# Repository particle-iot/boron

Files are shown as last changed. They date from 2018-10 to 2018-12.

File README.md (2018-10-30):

# Boron

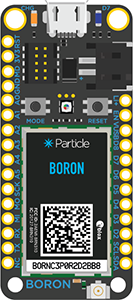
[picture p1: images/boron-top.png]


### Overview

The Boron LTE is a powerful LTE CAT-M1/NB1 enabled development kit that can act as either a standalone cellular endpoint or LTE enabled gateway for Particle Mesh networks. It is based on the Nordic nRF52840 and has built-in battery charging circuitry so it’s easy to connect a Li-Po and deploy your local network in minutes.

The Boron is great for connecting existing projects to the Particle Device Cloud or as a gateway to connect an entire group of local endpoints where Wi-Fi is missing or unreliable.

### Features

* u-blox SARA R410 LTE modem (Boron LTE)
  * LTE CAT M1/ NB1 module with global hardware support (MVNO support for US only) 
  * 3GPP Release 13 LTE Cat M1 
* u-blox SARA U201 2G/3G modem (Boron 2G/3G)
  * HSPA/GSMqq with global hardware and SIM support 
  * Bands 800/850/900/1900/2100 MHz 
  * 3GPP Release 7 
* Nordic Semiconductor nRF52840 SoC 
  * ARM Cortex-M4F 32-bit processor @ 64MHz 
  * 1MB flash, 256KB RAM 
  * IEEE 802.15.4-2006: 250 Kbps 
  * Bluetooth 5: 2 Mbps, 1 Mbps, 500 Kbps, 125 Kbps 
  * Supports DSP instructions, HW accelerated Floating Point Unit (FPU) calculations 
  * ARM TrustZone CryptoCell-310 Cryptographic and security module 
  * Up to +8 dBm TX power (down to -20 dBm in 4 dB steps) 
  * NFC-A tag
* On-board additional 2MB SPI flash
* 20 mixed signal GPIO (6 x Analog, 8 x PWM), UART, I2C, SPI
* Micro USB 2.0 full speed (12 Mbps)
* Integrated Li-Po charging and battery connector
* JTAG (SWD) Connector
* RGB status LED
* Reset and Mode buttons
* Dual SIM support: Nano 4FF and MFF2
* On-board PCB antenna
* u.FL connector for external antenna
* Meets the Adafruit Feather [specification](https://learn.adafruit.com/adafruit-feather/feather-specification) in dimensions and pinout
* FCC and PTCRB certified
* RoHS compliant (lead-free)

### Structure of this repository:
 - /eagle
     + Contains the schematic and PCB files in the Eagle file format
 - /gerbers
     + Contains the manufacturing gerber files for the board
 - /datasheets
     + Contains the relevant datasheets of the components used on the Boron
 - /pdfs
     + Contains schematic files in PDF 

### Hardware datasheet

The complete datasheet for the Boron is available [here.](https://docs.particle.io/datasheets/cellular/boron-datasheet/
)

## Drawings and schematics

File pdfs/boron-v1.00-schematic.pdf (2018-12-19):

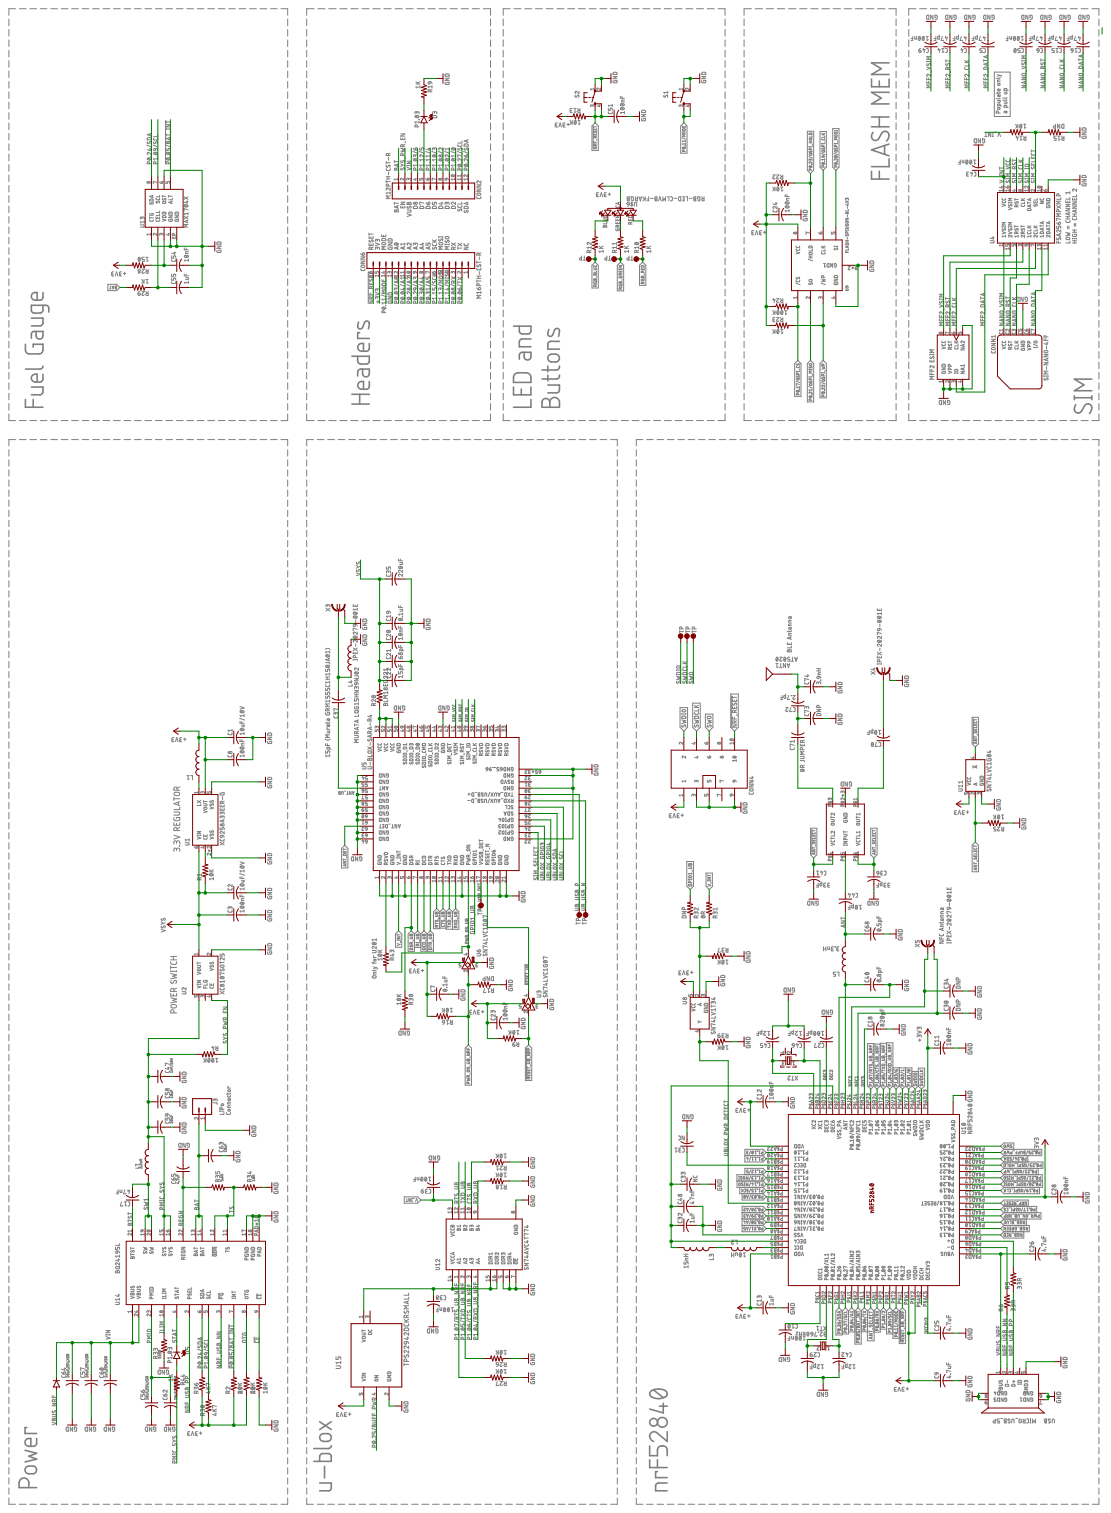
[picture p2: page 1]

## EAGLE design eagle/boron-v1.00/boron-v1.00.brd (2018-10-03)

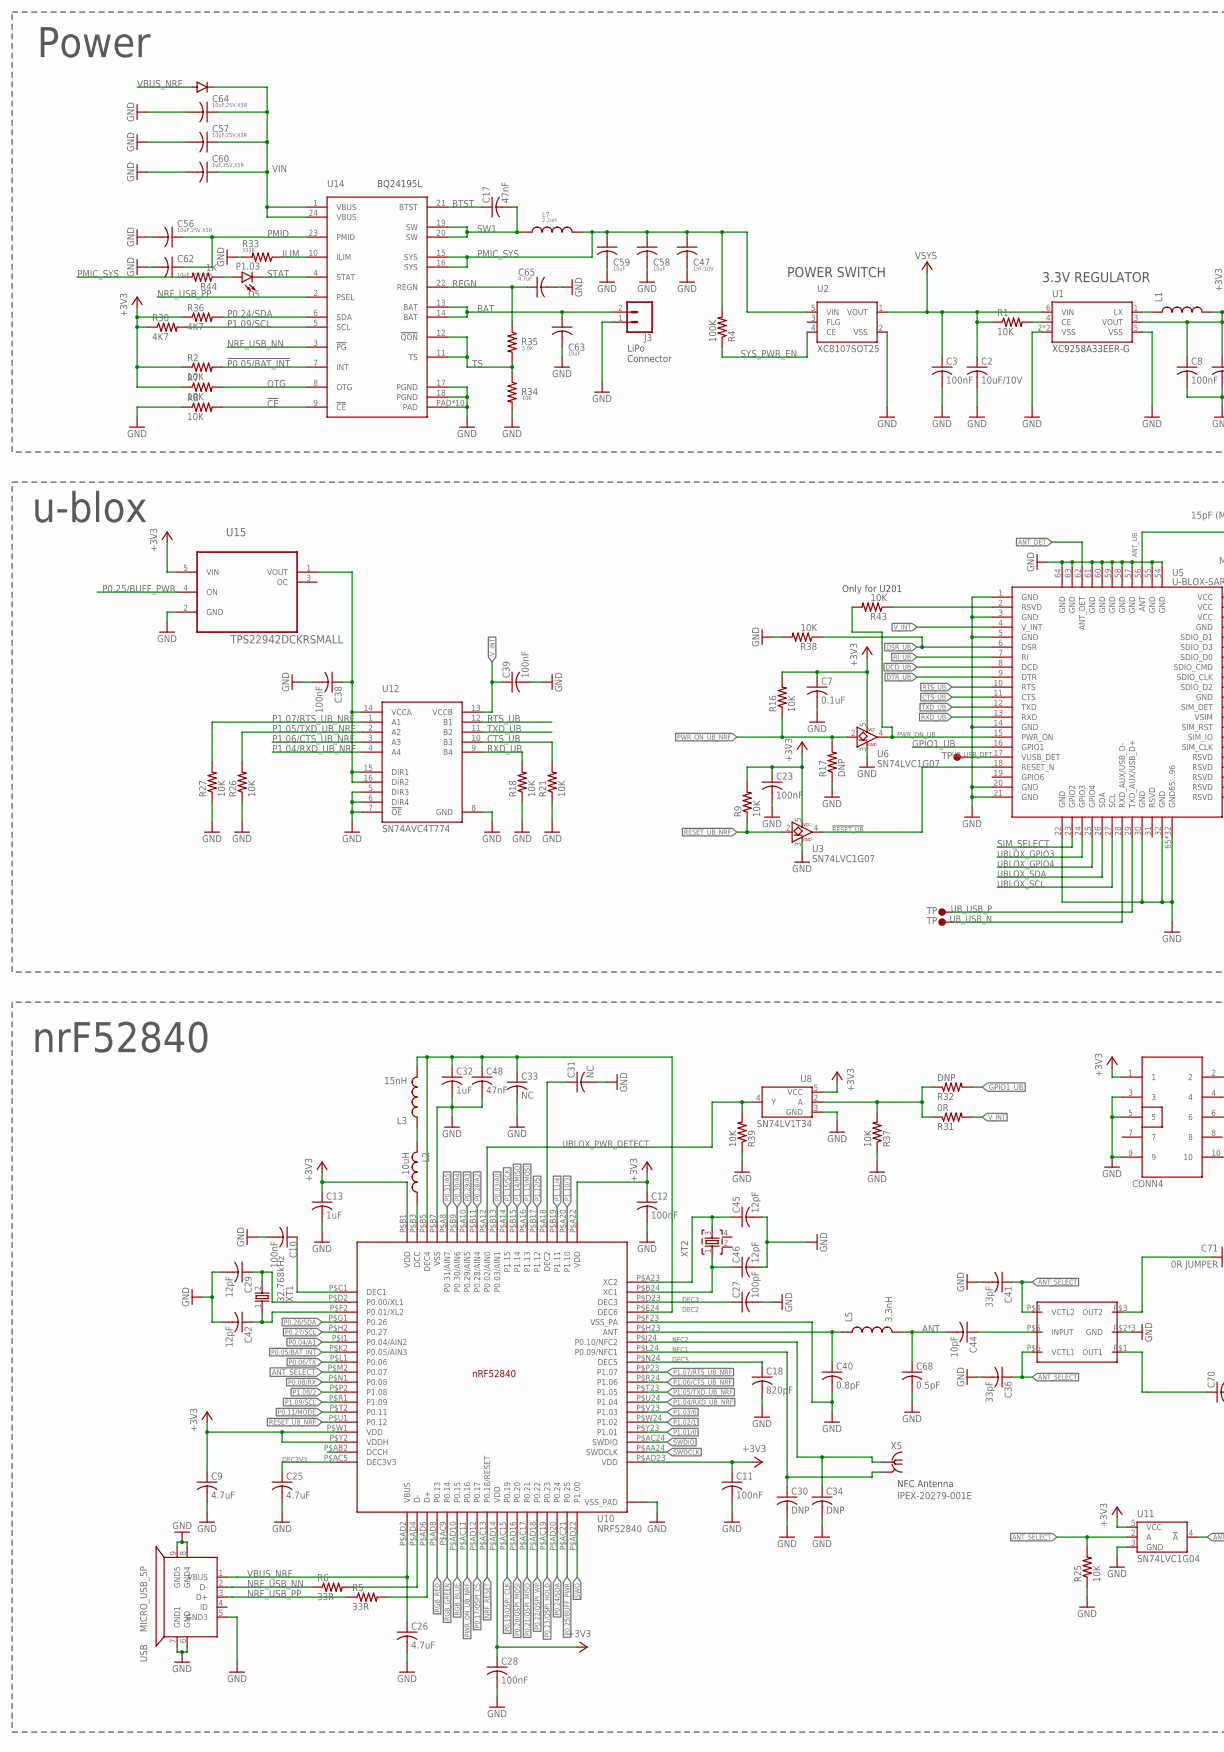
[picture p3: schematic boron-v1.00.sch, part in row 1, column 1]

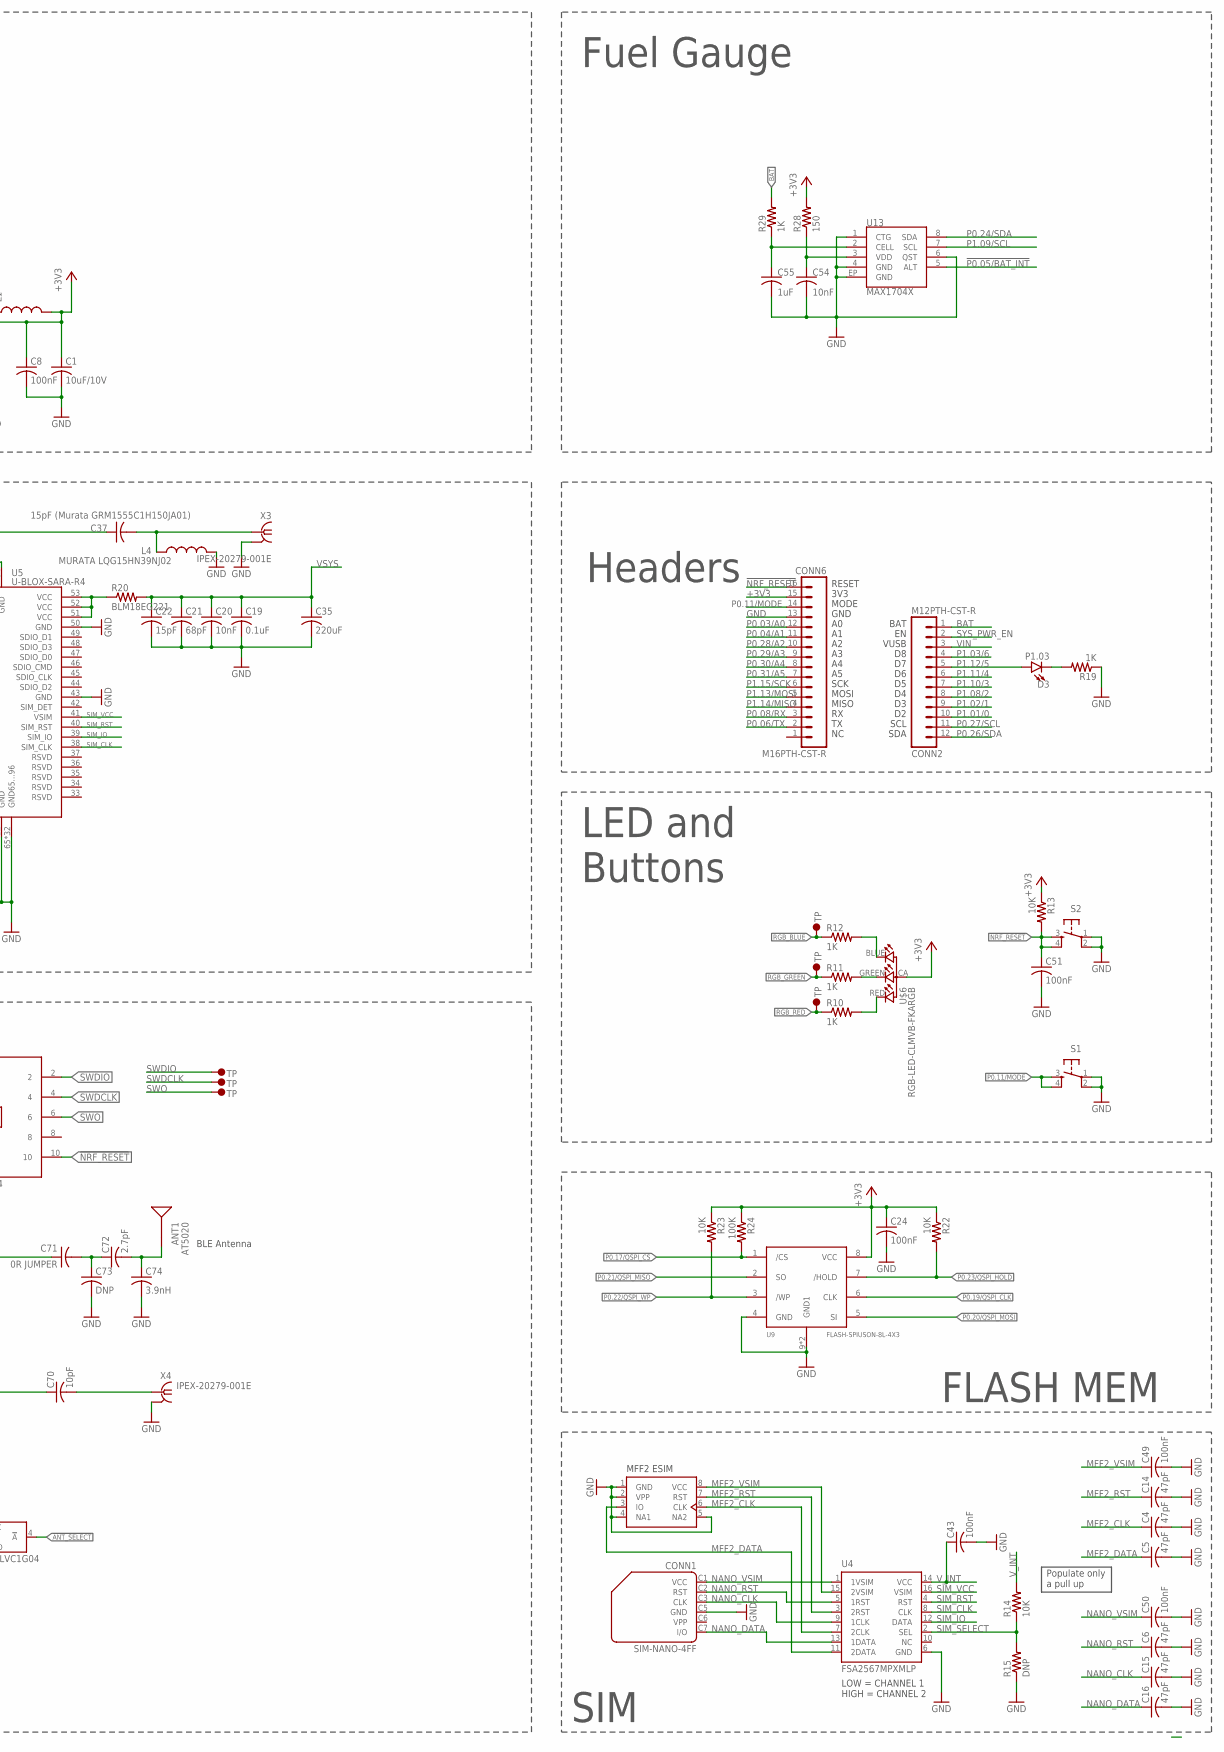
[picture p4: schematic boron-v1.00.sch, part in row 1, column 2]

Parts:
ANT1: AT5020
C1, C2: 10uF/10V; C0603K
C3: 100nF; C0603K
C4, C5, C6, C14, C15, C16: 47pF; C0201_B
C7, C19: 0.1uF; C0402_B
C8, C10, C11, C12, C23, C24, C28, C38, C39, C43, C49, C50, C51: 100nF; C0201_B
C9, C25, C26: 4.7uF; C0402
C13: 1uF; C0402
C17, C48: 47nF; C0201_B
C18: 820pF; C0201_B
C20, C54: 10nF; C0402_B
C21: 68pF; C0402_B
C22: 15pF; C0402_B
C27: 100pF; C0201_B
C29, C42, C45, C46: 12pF; C0201_B
C30, C34, C73: DNP; C0201_B
C31, C33: NC; C0201_B
C32: 1uF; C0402K
C35: 220uF; C1210
C36, C41: 33pF; C0201_B
C37: 15pF (Murata GRM1555C1H150JA01); C0402_B
C40: 0.8pF; C0201_B
C44, C70: 10pF; C0201_B
C47: 1nF/10V; C0402_B
C55: 1uF; C0402_B
C56, C57, C62, C64: 10uF,25V,X5R; C0603_B
C58, C59, C63: 10uF; C0603_B
C60: 1uF,25V,X5R; C0603_B
C65: 4.7uF; C0603_B
C68: 0.5pF; C0201_B
C71: 0R JUMPER; C0201_B
C72: 2.7pF; C0201_B
C74: 3.9nH; C0201_B
CONN1: SIM-NANO-4FF; GCT-SIM8100
CONN2: M12PTH-CST-R; 1X12-CASTELLATED
CONN4: CONN5X2; CONN5X2_1.27
CONN6: M16PTH-CST-R; 1X16-CASTELLATED
D3, D5: P1.03; LED-0603
D4: DIODE_NT; DIODE-DO-220AA_NT(SMP)
J3: CONN_02-JST-2MM-SMT; JST-2-SMD@2
L1: INDUCTOR-SPARKFUNVLS3012ET-4R7M; INDUCTOR-VLS-E
L2: 10uH; RESC0603_L
L3: 15nH; C0402_B
L4: MURATA LQG15HN39NJ02; C0402_B
L5: 3.3nH; C0402_B
L7: 2.2uH; INDUCTOR-4040
R1, R2, R7, R8, R9, R13, R14, R16, R18, R21, R22, R23, R25, R26, R27, R37, R38, R39, R43: 10K; C0201_B
R4, R24: 100K; C0201_B
R5, R6: 33R; C0201_B
R10, R11, R12, R19, R44: 1K; C0201_B
R15, R17, R32: DNP; C0201_B
R20: BLM18EG221; R0603
R28: 150; 0402-RES
R29: 1K; 0402-RES
R30, R36: 4K7; C0201_B
R31: 0R; C0201_B
R33: 333R; R0402_B
R34: 10K; R0402_B
R35: 5.6K; R0402_B
S1, S2: TAC_SWITCHSMD; TACTILE_SWITCH_SMD
U1: XC9258A33EER-G; USP-6C
U2: XC8107SOT25; SOT25
U3, U6: SN74LVC1G07; SC-70-5
U4: FSA2567MPXMLP; MLP16
U5: U-BLOX-SARA-R4; U-BLOX-SARA-U2
U7: ESIMSON8; MFF2
U8: SN74LV1T34; SC70-5
U9: FLASH-SPIUSON-8L-4X3; USON8-3X4
U10: NRF52840; AQFN50P700X700X85_HS-74N
U11: SN74LVC1G04; SC70-5
U12: SN74AVC4T774; UFQFN-16
U13: MAX1704X; TDFN-8
U14: BQ24195L; QFN24
U15: TPS22942DCKRSMALL; SC70-5
U$1, U$4, U$5, U$9, U$10, U$11, U$18, U$19, U$20: TP5; TP30_TOP
U$6: RGB-LED-CLMVB-FKARGB; PLCC4-2MM-RGB
U$7: SKY13351-378LF; MLPD-6-1X1
USB: MICRO_USB_5P; MICRO_USB
X3, X4, X5: IPEX-20279-001E
XT1: 32.768kHz; XTAL_3215_N
XT2: XTAL_32MHZ; BT-XTAL_2016_N

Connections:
!ANT_SELECT: C41.1, U11.4 (!A), U$7.P$4 (VCTL2)
!CE: R8.2, U14.9 (!CE)
!NRF_RESET: C51.1, CONN4.10, CONN6.16, R13.2, S2.3, S2.4, U10.P$AC13 (P0.18/RESET)
!P0.05/BAT_INT: R2.2, U10.P$K2 (P0.05/AIN3), U13.5 (ALT), U14.7 (INT)
!RESET_UB: U3.4 (B), U5.18 (RESET_N)
!RESET_UB_NRF: R9.1, U3.2 (A), U10.P$U1 (P0.12)
+3V3: C1.1, C7.1, C8.1, C9.1, C11.1, C12.1, C13.1, C23.1, C24.1, C28.1, CONN4.1, CONN6.15, L1.P$2 (2), R2.1, R7.1, R9.2, R13.1, R16.2, R22.1, R23.1, R24.1, R28.2, R30.1, R36.1, U1.3 (VOUT), U3.5 (VCC), U6.5 (VCC), U8.5 (VCC), U9.8 (VCC), U10.P$A22 (VDD), U10.P$AD14 (VDD), U10.P$AD23 (VDD), U10.P$B1 (VDD), U10.P$W1 (VDD), U10.P$Y2 (VDDH), U11.5 (VCC), U15.5 (VIN), U$6.CA (1)
ANT: C44.2, C68.1, L5.2
ANT_DET: U5.62 (ANT_DET)
ANT_SELECT: C36.1, R25.2, U10.P$M2 (P0.07), U11.2 (A), U$7.P$6 (VCTL1)
ANT_UB: C37.1, U5.56 (ANT)
BAT: C63.1, CONN2.1, J3.2 (1), R29.2, U14.13 (BAT), U14.14 (BAT)
BTST: C17.1, U14.21 (BTST)
CTS_UB: R21.2, U5.11 (CTS), U12.10 (B3)
DCC: L2.1, U10.P$B3 (DCC)
DCD_UB: U5.8 (DCD)
DEC2: C32.1, C33.1, C48.1, L3.2, U10.P$B5 (DEC4), U10.P$E24 (DEC6)
DEC3: C27.1, U10.P$D23 (DEC3)
DEC3V3: C25.1, U10.P$AC5 (DEC3V3)
DEC5: C18.1, U10.P$N24 (DEC5)
DSR_UB: R38.1, U5.6 (DSR)
DTR_UB: U5.9 (DTR)
GND: C1.2, C2.2, C3.2, C4.2, C5.2, C6.2, C7.2, C8.2, C9.2, C10.2, C11.2, C12.2, C13.2, C14.2, C15.2, C16.2, C18.2, C19.2, C20.2, C21.2, C22.2, C23.2, C24.2, C25.2, C26.2, C27.2, C28.2, C29.2, C30.2, C31.2, C32.2, C33.2, C34.2, C35.2, C36.2, C38.2, C39.2, C40.2, C41.2, C42.2, C43.2, C45.2, C46.2, C47.2, C48.2, C49.2, C50.2, C51.2, C54.2, C55.2, C56.2, C57.2, C58.2, C59.2, C60.2, C62.2, C63.2, C64.2, C65.2, C68.2, C73.2, C74.2, CONN1.C5 (GND), CONN4.3, CONN4.5, CONN4.9, CONN6.13, J3.1 (2), L4.2, R8.1, R15.1, R17.1, R18.1, R19.1, R21.1, R25.1, R26.1, R27.1, R33.2, R34.2, R37.1, R38.2, R39.1, S1.1, S1.2, S2.1, S2.2, U1.2 (VSS), U1.5 (VSS), U1.P$1 (VSS), U2.2 (VSS), U3.3 (GND), U4.6 (GND), U5.1 (GND), U5.3 (GND), U5.5 (GND), U5.14 (GND), U5.20 (GND), U5.21 (GND), U5.22 (GND), U5.30 (GND), U5.32 (GND), U5.43 (GND), U5.50 (GND), U5.54 (GND), U5.55 (GND), U5.57 (GND), U5.58 (GND), U5.59 (GND), U5.60 (GND), U5.61 (GND), U5.63 (GND), U5.64 (GND), U5.65 (GND65...96), U5.66 (GND65...96), U5.67 (GND65...96), U5.68 (GND65...96), U5.69 (GND65...96), U5.70 (GND65...96), U5.71 (GND65...96), U5.72 (GND65...96), U5.73 (GND65...96), U5.74 (GND65...96), U5.75 (GND65...96), U5.76 (GND65...96), U5.77 (GND65...96), U5.78 (GND65...96), U5.79 (GND65...96), U5.80 (GND65...96), U5.81 (GND65...96), U5.82 (GND65...96), U5.83 (GND65...96), U5.84 (GND65...96), U5.85 (GND65...96), U5.86 (GND65...96), U5.87 (GND65...96), U5.88 (GND65...96), U5.89 (GND65...96), U5.90 (GND65...96), U5.91 (GND65...96), U5.92 (GND65...96), U5.93 (GND65...96), U5.94 (GND65...96), U5.95 (GND65...96), U5.96 (GND65...96), U6.3 (GND), U7.1 (GND), U7.2 (VPP), U7.4 (NA1), U7.5 (NA2), U8.3 (GND), U9.4 (GND), U9.9 (GND1), U9.10 (GND1), U10.P$74 (VSS_PAD), U10.P$75 (VSS_PAD), U10.P$76 (VSS_PAD), U10.P$77 (VSS_PAD), U10.P$78 (VSS_PAD), U10.P$79 (VSS_PAD), U10.P$80 (VSS_PAD), U10.P$81 (VSS_PAD), U10.P$82 (VSS_PAD), U10.P$83 (VSS_PAD), U10.P$B7 (VSS), U10.P$F23 (VSS_PA), U11.3 (GND), U12.5 (DIR3), U12.6 (DIR4), U12.7 (!OE), U12.8 (GND), U13.1 (CTG), U13.4 (GND), U13.6 (QST), U13.EP (GND), U14.17 (PGND), U14.18 (PGND), U14.PAD, U14.PAD@1 (PAD), U14.PAD@2 (PAD), U14.PAD@3 (PAD), U14.PAD@4 (PAD), U14.PAD@5 (PAD), U14.PAD@6 (PAD), U14.PAD@7 (PAD), U14.PAD@8 (PAD), U14.PAD@9 (PAD), U15.2 (GND), U$7.P$2 (GND), U$7.P$7 (GND), U$7.P$8 (GND), USB.5 (GND3), USB.6 (GND), USB.7 (GND1), USB.8 (GND4), USB.9 (GND5), X3.2@1 (GND), X3.2@2 (GND), X4.2@1 (GND), X4.2@2 (GND)
GPIO1_UB: R32.2, U5.16 (GPIO1)
ILIM: R33.1, U14.10 (ILIM)
MFF2_CLK: C4.1, U4.7 (2CLK), U7.6 (CLK)
MFF2_DATA: C5.1, U4.11 (2DATA), U7.3 (IO)
MFF2_RST: C14.1, U4.3 (2RST), U7.7 (RST)
MFF2_VSIM: C49.1, U4.15 (2VSIM), U7.8 (VCC)
unnamed: C37.2, L4.1, X3.1
unnamed: C44.1, U$7.P$5 (INPUT)
unnamed: R12.2, U$6.BLUE (2)
unnamed: C38.1, U12.14 (VCCA), U12.15 (DIR1), U12.16 (DIR2), U15.1 (VOUT)
unnamed: R11.2, U$6.GREEN (3)
unnamed: R20.1, U5.51 (VCC), U5.52 (VCC), U5.53 (VCC)
unnamed: R10.2, U$6.RED (4)
unnamed: C70.1, U$7.P$1 (OUT1)
unnamed: C40.1, L5.1, U10.P$H23 (ANT)
unnamed: R31.1, R32.1, R37.2, U8.2 (A)
unnamed: D5.A, R44.1
unnamed: R1.2, U1.4 (CE)
unnamed: D3.C, R19.2
unnamed: L1.P$1 (1), U1.1 (LX)
unnamed: C31.1, U10.P$A18 (DEC2)
unnamed: C71.1, U$7.P$3 (OUT2)
unnamed: C70.2, X4.1
unnamed: C71.2, C72.1, C73.1
unnamed: R43.1, U5.2 (RSVD)
unnamed: ANT1.1, C72.2, C74.1
unnamed: C54.1, R28.1, U13.3 (VDD)
unnamed: C55.1, R29.1, U13.2 (CELL)
unnamed: C10.1, U10.P$C1 (DEC1)
unnamed: L2.2, L3.1
NANO_CLK: C15.1, CONN1.C3 (CLK), U4.9 (1CLK)
NANO_DATA: C16.1, CONN1.C7 (I/O), U4.13 (1DATA)
NANO_RST: C6.1, CONN1.C2 (RST), U4.5 (1RST)
NANO_VSIM: C50.1, CONN1.C1 (VCC), U4.1 (1VSIM)
NFC1: C30.1, U10.P$L24 (P0.09/NFC1), X5.2@1 (GND), X5.2@2 (GND)
NFC2: C34.1, U10.P$J24 (P0.10/NFC2), X5.1
NRF_USB_N: R6.2, U10.P$AD4 (D-)
NRF_USB_NN: R6.1, U14.3 (!PG), USB.2 (D-)
NRF_USB_P: R5.2, U10.P$AD6 (D+)
NRF_USB_PP: R5.1, U14.2 (PSEL), USB.3 (D+)
OTG: R7.2, U14.8 (OTG)
P0.03/A0: CONN6.12, U10.P$B13 (P0.03/AIN1)
P0.04/A1: CONN6.11, U10.P$J1 (P0.04/AIN2)
P0.06/TX: CONN6.2, U10.P$L1 (P0.06)
P0.08/RX: CONN6.3, U10.P$N1 (P0.08)
P0.11/MODE: CONN6.14, S1.3, S1.4, U10.P$T2 (P0.11)
P0.17/QSPI_CS: R24.2, U9.1 (/CS), U10.P$AD12 (P0.17)
P0.19/QSPI_CLK: U9.6 (CLK), U10.P$AC15 (P0.19)
P0.20/QSPI_MOSI: U9.5 (SI), U10.P$AD16 (P0.20)
P0.21/QSPI_MISO: U9.2 (SO), U10.P$AC17 (P0.21)
P0.22/QSPI_WP: R23.2, U9.3 (/WP), U10.P$AD18 (P0.22)
P0.23/QSPI_HOLD: R22.2, U9.7 (/HOLD), U10.P$AC19 (P0.23)
P0.24/SDA: R36.2, U10.P$AD20 (P0.24), U13.8 (SDA), U14.6 (SDA)
P0.25/BUFF_PWR: U10.P$AC21 (P0.25), U15.4 (ON)
P0.26/SDA: CONN2.12, U10.P$G1 (P0.26)
P0.27/SCL: CONN2.11, U10.P$H2 (P0.27)
P0.28/A2: CONN6.10, U10.P$B11 (P0.28/AIN4)
P0.29/A3: CONN6.9, U10.P$A10 (P0.29/AIN5)
P0.30/A4: CONN6.8, U10.P$B9 (P0.30/AIN6)
P0.31/A5: CONN6.7, U10.P$A8 (P0.31/AIN7)
P1.01/0: CONN2.10, U10.P$Y23 (P1.01)
P1.02/1: CONN2.9, U10.P$W24 (P1.02)
P1.03/6: CONN2.4, U10.P$V23 (P1.03)
P1.04/RXD_UB_NRF: U10.P$U24 (P1.04), U12.4 (A4)
P1.05/TXD_UB_NRF: R26.2, U10.P$T23 (P1.05), U12.2 (A2)
P1.06/CTS_UB_NRF: U10.P$R24 (P1.06), U12.3 (A3)
P1.07/RTS_UB_NRF: R27.2, U10.P$P23 (P1.07), U12.1 (A1)
P1.08/2: CONN2.8, U10.P$P2 (P1.08)
P1.09/SCL: R30.2, U10.P$R1 (P1.09), U13.7 (SCL), U14.5 (SCL)
P1.10/3: CONN2.7, U10.P$A20 (P1.10)
P1.11/4: CONN2.6, U10.P$B19 (P1.11)
P1.12/5: CONN2.5, D3.A, U10.P$B17 (P1.12)
P1.13/MOSI: CONN6.5, U10.P$A16 (P1.13)
P1.14/MISO: CONN6.4, U10.P$B15 (P1.14)
P1.15/SCK: CONN6.6, U10.P$A14 (P1.15)
PMIC_SYS: C47.1, C58.1, C59.1, L7.P$2 (2), R4.2, R44.2, U2.5 (VIN), U14.15 (SYS), U14.16 (SYS)
PMID: C56.1, C62.1, U14.23 (PMID)
PWR_ON_UB: R43.2, U5.15 (PWR_ON), U6.4 (B)
PWR_ON_UB_NRF: R16.1, R17.2, U6.2 (A), U10.P$AC11 (P0.16)
REGN: C65.1, R35.1, U14.22 (REGN)
RGB_BLUE: R12.1, U10.P$AD10 (P0.15), U$11.P$1
RGB_GREEN: R11.1, U10.P$AC9 (P0.14), U$10.P$1
RGB_RED: R10.1, U10.P$AD8 (P0.13), U$9.P$1
RI_UB: U5.7 (RI)
RTS_UB: U5.10 (RTS), U12.12 (B1)
RXD_UB: R18.2, U5.13 (RXD), U12.9 (B4)
SIM_CLK: U4.8 (CLK), U5.38 (SIM_CLK)
SIM_IO: U4.12 (DATA), U5.39 (SIM_IO)
SIM_RST: U4.4 (RST), U5.40 (SIM_RST)
SIM_SELECT: R14.1, R15.2, U4.2 (SEL), U5.23 (GPIO2)
SIM_VCC: U4.16 (VSIM), U5.41 (VSIM)
STAT: D5.C, U14.4 (STAT)
SW1: C17.2, L7.P$1 (1), U14.19 (SW), U14.20 (SW)
SWDCLK: CONN4.4, U10.P$AA24 (SWDCLK), U$4.P$1
SWDIO: CONN4.2, U10.P$AC24 (SWDIO), U$1.P$1
SWO: CONN4.6, U10.P$AD22 (P1.00), U$5.P$1
SYS_PWR_EN: CONN2.2, R4.1, U2.4 (CE)
TS: R34.1, R35.2, U14.11 (TS), U14.12 (!QON)
TXD_UB: U5.12 (TXD), U12.11 (B2)
UBLOX_GPIO3: U5.24 (GPIO3)
UBLOX_GPIO4: U5.25 (GPIO4)
UBLOX_PWR_DETECT: R39.2, U8.4 (Y), U10.P$A12 (P0.02/AIN0)
UBLOX_SCL: U5.27 (SCL)
UBLOX_SDA: U5.26 (SDA)
UB_USB_DET: U5.17 (VUSB_DET), U$20.P$1
UB_USB_N: U5.28 (RXD_AUX/USB_D-), U$19.P$1
UB_USB_P: U5.29 (TXD_AUX/USB_D+), U$18.P$1
VBUS_NRF: C26.1, D4.ANODE, U10.P$AD2 (VBUS), USB.1 (VBUS)
VIN: C57.1, C60.1, C64.1, CONN2.3, D4.CATHODE, U14.1 (VBUS), U14.24 (VBUS)
VSYS: C2.1, C3.1, C19.1, C20.1, C21.1, C22.1, C35.1, R1.1, R20.2, U1.6 (VIN), U2.1 (VOUT)
V_INT: C39.1, C43.1, R14.2, R31.2, U4.14 (VCC), U5.4 (V_INT), U12.13 (VCCB)
XC1: C46.1, U10.P$B24 (XC1), XT2.1
XC2: C45.1, U10.P$A23 (XC2), XT2.3
XL1: C29.1, U10.P$D2 (P0.00/XL1), XT1.2
XL2: C42.1, U10.P$F2 (P0.01/XL2), XT1.1

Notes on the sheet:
MISO
MOSI
SCK
GND
MODE
3V3
RESET
SDA
SCL
VUSB
BAT
NFC Antenna
BLE Antenna
MFF2 ESIM
Populate only a pull up
3.3V REGULATOR
LiPo Connector
nrF52840
u-blox
Power
Headers
LED and Buttons
FLASH MEM
SIM
Fuel Gauge
Only for U201
LOW = CHANNEL 1 HIGH = CHANNEL 2
POWER SWITCH

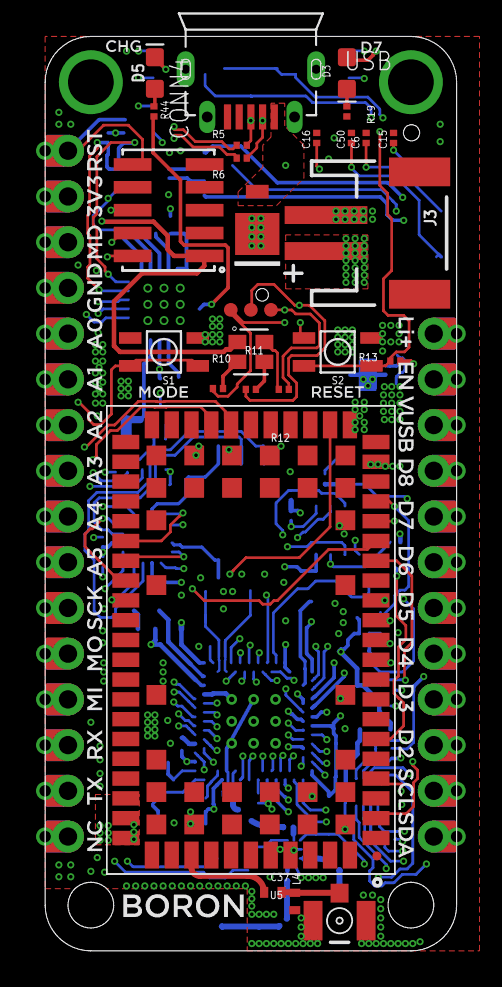
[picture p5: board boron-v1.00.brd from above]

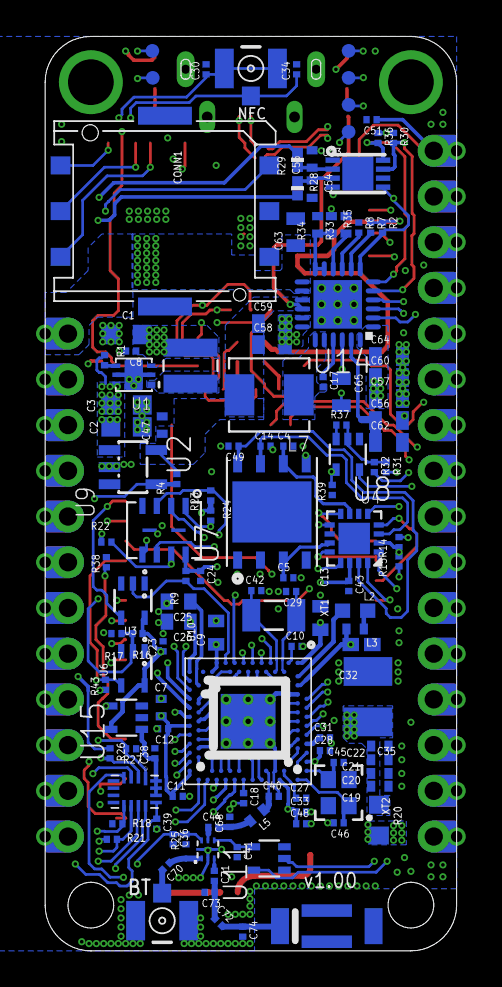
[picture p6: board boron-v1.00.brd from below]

Board: 8 copper layers, 22.9 x 50.8 mm, 157 parts (129 on the bottom side), 130 nets.

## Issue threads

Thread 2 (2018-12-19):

missing schematics

pabigot, 2018-12-19:
The argon and xenon repositories have the schematics in PDF form.  Would it be feasible to add them for boron as well?

rickkas7, 2018-12-19:
Sure. I just added the Boron schematic in pdf format in the pdfs directory.

jacky4566, 2019-09-25:
Hate to nag but can we get the PDF in a searchable format. It can be difficult to find rails and pins otherwise.
Adobe OCR seems to fail on that pdf.

Closed 2018-12-19.

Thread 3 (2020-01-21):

nRF52840 footprint and vias under thermal pad

xeanhort, 2020-01-21:
Hi, I've noticed that the nRF52840 footprint doesn't follow the Nordic's recomendation regarding the thermal pad under the chip (shorter than the recomended). The vias under the micro can collide with the GND from the thermal pad (even with tented vias).

- Nordic DK board:
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.
- Boron gerber files (highlighted green the real thermal pad):
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.

Are you aware of that? How did you managed to ensure the correct operability?

Thank you!

irrabb, 2020-02-01:
Hi!

I've noticed the exact same thing, and I don't really understand how the Boron HW can work properly.

I've checked also with de Nordic's nRF52840 development board PCB, and the footprint is bigger (like @xeanhort has also expressed).

Can you please solve this issue?
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

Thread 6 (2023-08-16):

Antenna filter on ANT pin

sigurdoyen, 2023-08-16:
On the devkit u-blox C030-R412M
schematic: https://os.mbed.com/media/uploads/ublox/c030-r412m-0-00_schematics.pdf
web site: https://os.mbed.com/platforms/ublox-C030-R412M/

There is no matching network between the ANT pin and the antenna connector, just a direct connection. I cannot find anything in the datasheet either about a matching network other than to use 50 ohm impedance.

Have you compared just having a 50 ohm trace directly from the pin to the connector vs. including the capacitor (15pf) and inductor (39nH) ?

Is it tested that the values used work well?

sigurdoyen, 2023-08-16:
> matching

Closed 2023-08-16.

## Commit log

2018-10-03 added design files
    [boron-v1.00.brd, boron-v1.00.sch]
2018-12-19 Add schematic pdf
2019-03-04 Include MX25L3233F SPI flash datasheet

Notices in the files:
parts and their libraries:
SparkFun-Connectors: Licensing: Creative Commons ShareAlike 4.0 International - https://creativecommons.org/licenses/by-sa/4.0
